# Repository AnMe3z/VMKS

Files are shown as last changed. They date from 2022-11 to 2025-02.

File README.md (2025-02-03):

# MECHKA v1
## By Budget Dynamics

MECHKA е четирикрак робот, който е създаден от екип Budget Dynamics. Той може да изпълнява различни интересни и полезни функции. Роботът има приложения в индустрията и образованието. Контролира се от мобилно приложение чрез Bluetooth. Проекта поначало е курсов проект по дисциплината "Вградени микрокомпютърни системи" - ВМКС, но екипът участва с него и във ТУЕС Фест 2023 (и печели първо място в него в категорията "ВМКС"), както и е приет с MECHKA в "PARA Robotics Incubator" сезон 2. Също участва и в Robo Days '23, където печели второ място в категорията "Роботика".

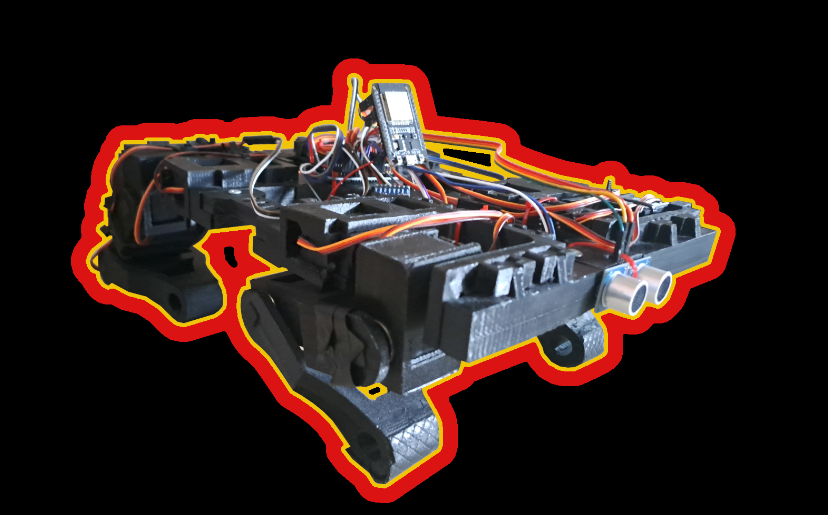
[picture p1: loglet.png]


## Съдържание
 
1. [Функции](#функции)  
2. [Документация на проекта](#Документация-на-проекта)       
3. [Презентация](#презентация)  
4. [Demо](#Demo)     
5. [Технологии](#Технологии)     
6. [Електрическа схема](#Електрическа-схема)   
7. [3D Модел на тялото](#3D-Модел-на-тялото)  
8. [ТУЕС Фест постер](#ТУЕС-Фест-постер)    
9. [Екипът Budget Dynamics](#Budget-Dynamics)  

## Функции

- Управление от мобилно приложение
- Изправяне, клякане
- Ходене
- Специални функции

## Документация на проекта

[Документация](https://docs.google.com/document/d/1ljFhPLfK0vJMqwFt7CCxIXQy4T2rVfxQFEeq_DpqxoI/edit)

## Презентация

[Презентация](https://docs.google.com/presentation/d/1ao5GaoYlJ3WwoU5Bq-MMPqkvP_JQxsr8S0_cT7X9GHs/edit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)

## Demo

[Демонстрация](https://www.youtube.com/watch?v=mcv_eNT28IA&t=1s&ab_channel=%D0%A2%D0%A3%D0%95%D0%A1)

## Технологии

- **Много математика**
- **Arduino Uno**
- **C/C++**
- **Android studio**
- **Java**

## Електрическа схема

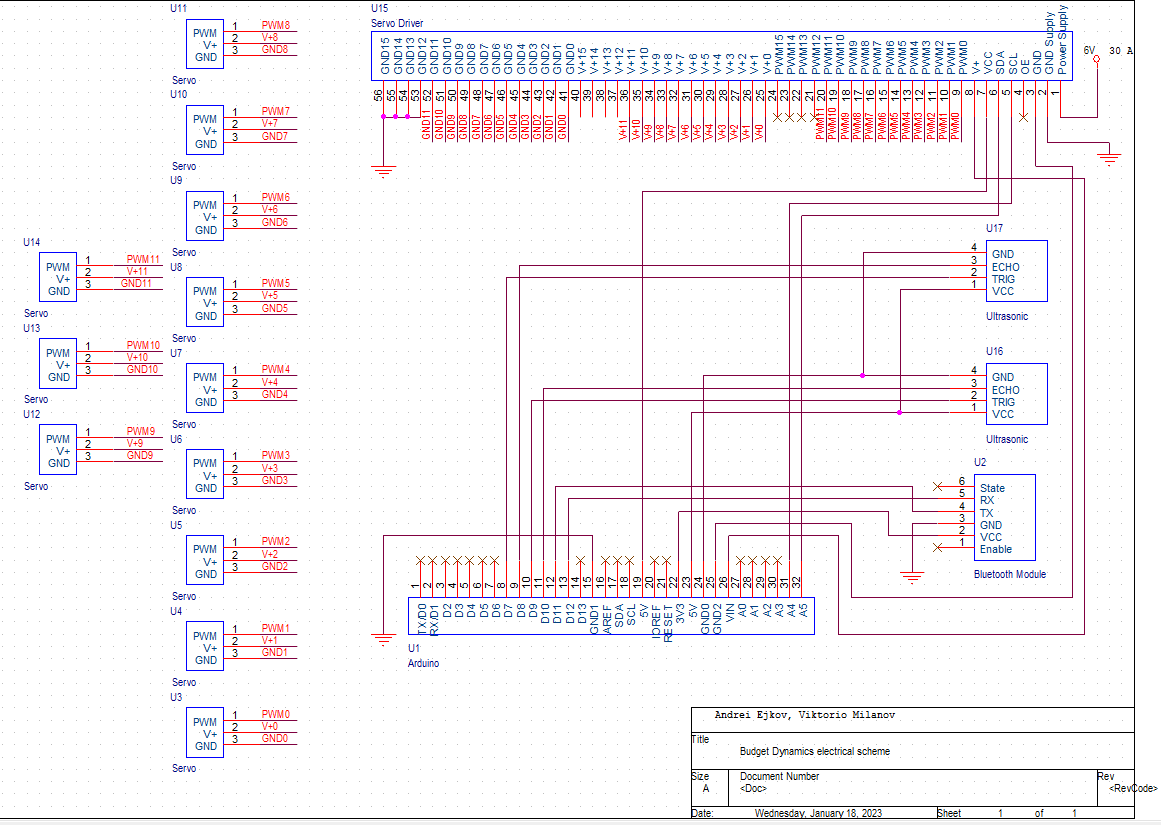
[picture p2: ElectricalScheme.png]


## 3D Модел на тялото

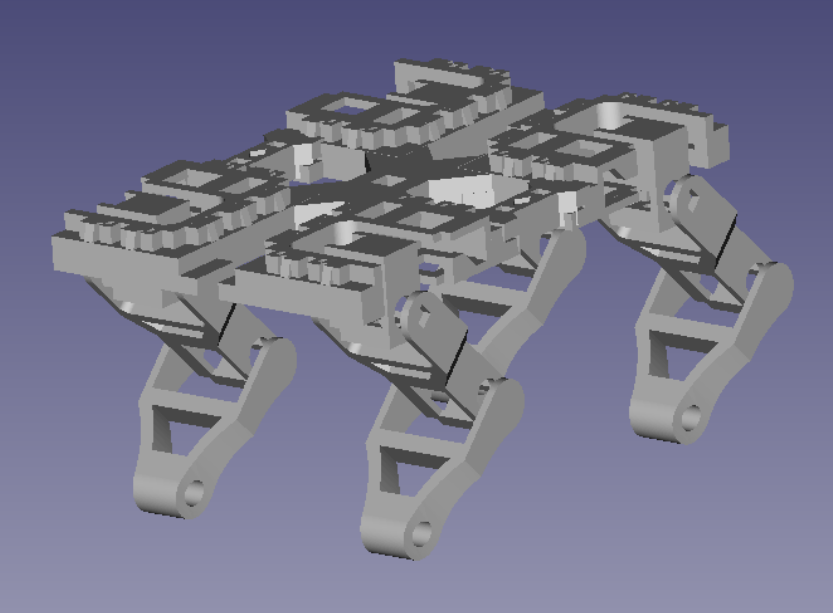
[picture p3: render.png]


## ТУЕС Фест постер



## Budget Dynamics

- [@Андрей Ежков](https://www.github.com/AnMe3z)
- [@Викторио Миланов](https://www.github.com/bigIq)

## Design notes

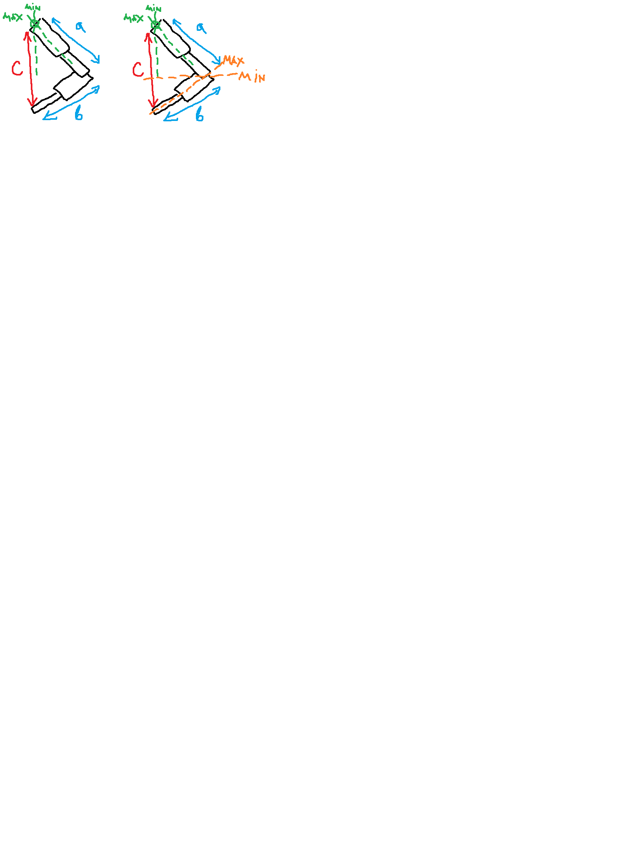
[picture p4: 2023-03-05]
code/other/stage1/servos/servo-lore.png

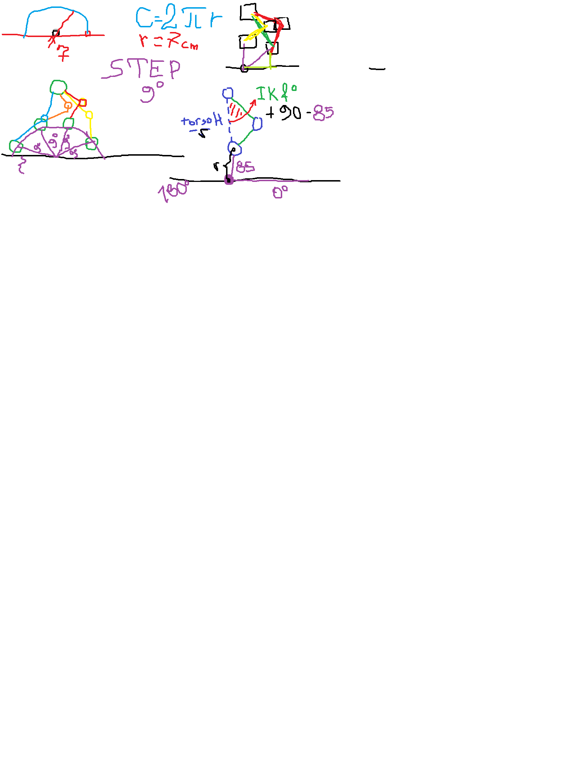
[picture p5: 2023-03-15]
code/other/stage1/servos/servo-walk-lore.png

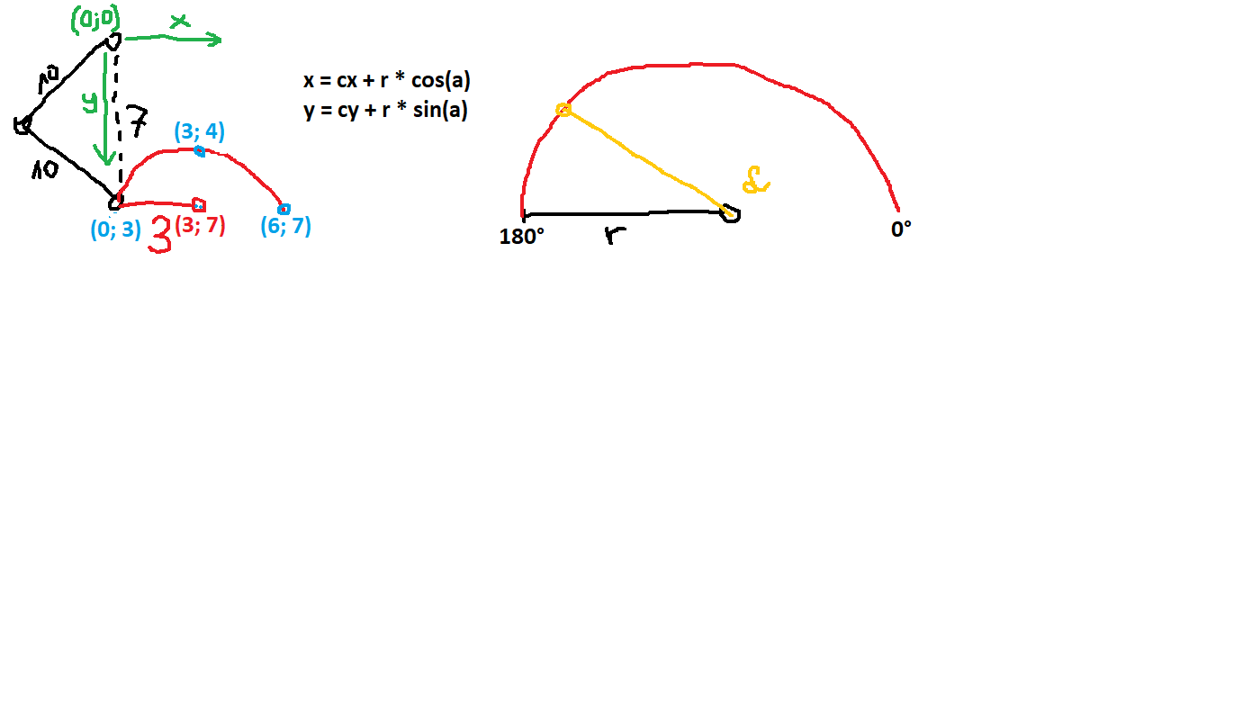
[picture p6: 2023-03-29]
code/other/stage1/servos/hodene-shemi.png

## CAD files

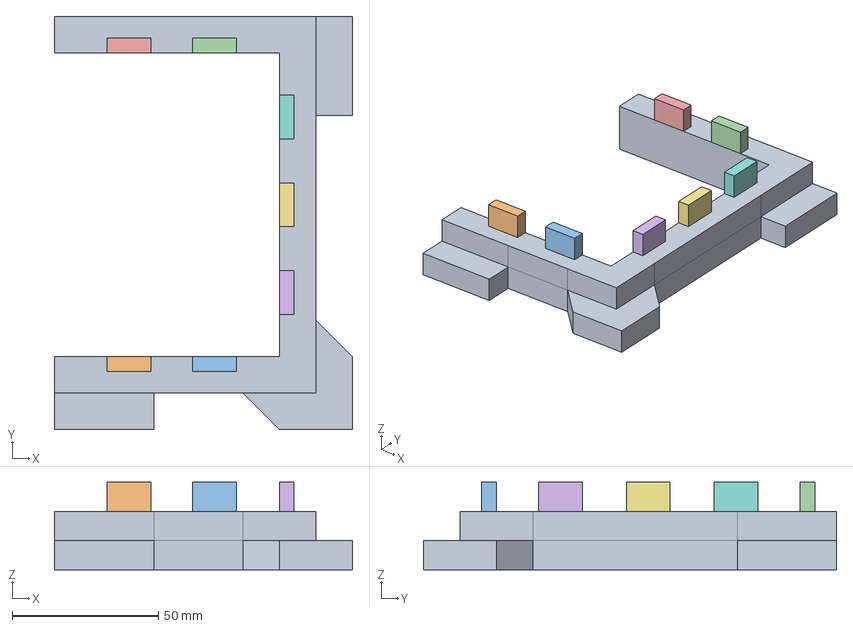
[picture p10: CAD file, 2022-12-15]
hardware/body/HipToBody(Without Full Connectors).FCStd
102.0 x 141.5 x 30.0 mm
MainMale
MaleCon1
MaleCon002
MaleCon004
MaleCon005
MaleCon006
MaleCon007
MaleCon008

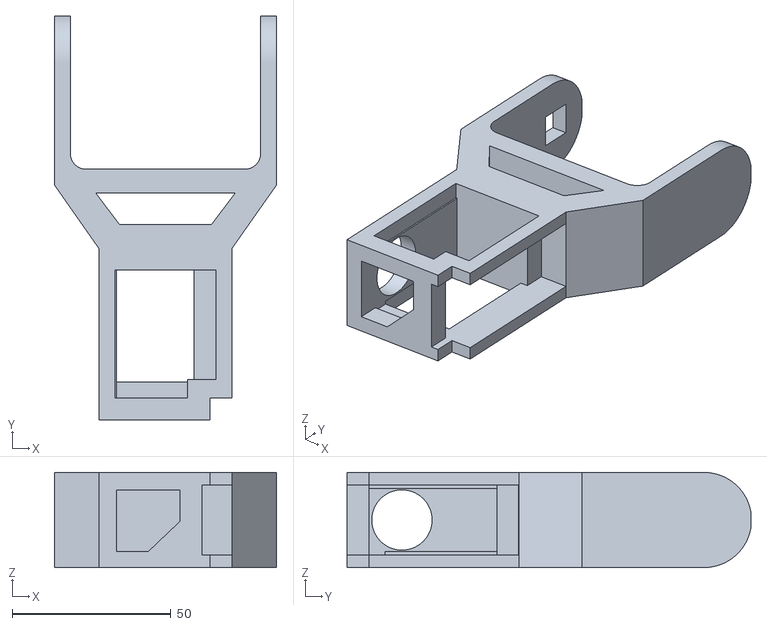
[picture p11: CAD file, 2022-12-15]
hardware/exports/femur-MainBody.stl
70.0 x 127.2 x 30.0

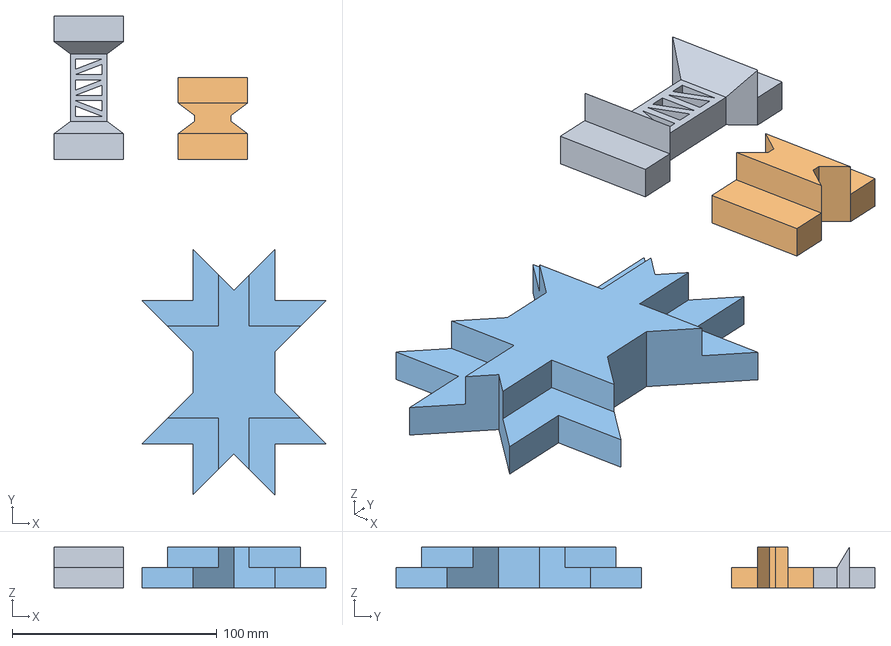
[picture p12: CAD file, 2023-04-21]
hardware/body/OtherBodyParts_Featherweight-fixed.FCStd
132.9 x 234.0 x 20.0 mm
I
I2 (4cm)
Star

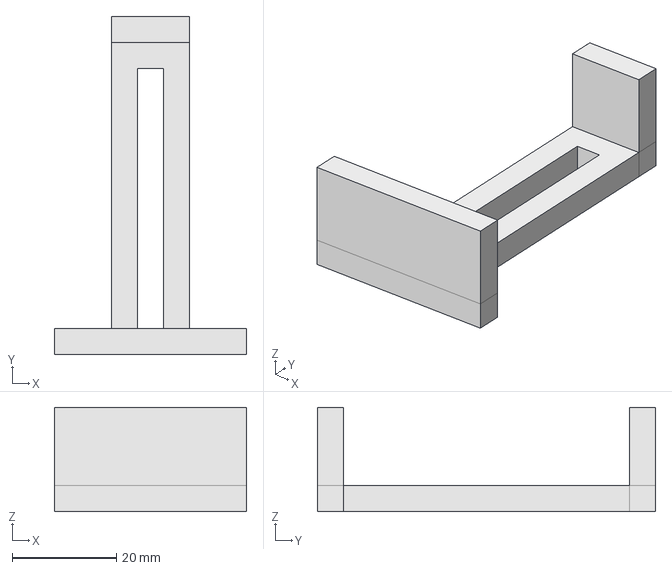
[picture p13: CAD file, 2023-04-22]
hardware/exo(rollcage)/hc-05-holder.FCStd
37.0 x 65.0 x 20.0 mm

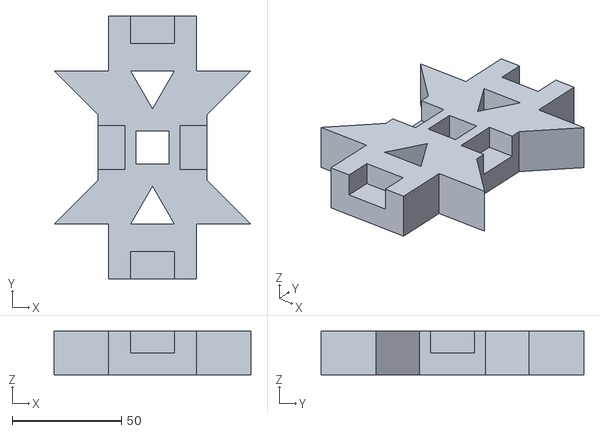
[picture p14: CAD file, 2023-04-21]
hardware/exports/exoskeleton parts-Star.stl
90.0 x 120.0 x 20.0

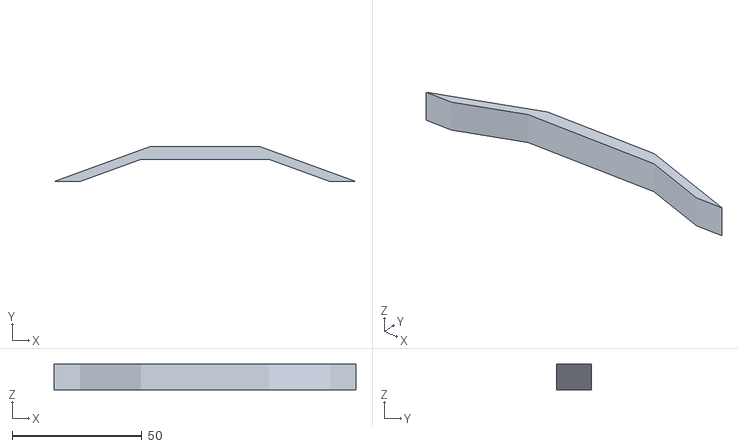
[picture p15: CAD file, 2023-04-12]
hardware/holders/ultrasonicHolderTRUST.stl
116.5 x 13.6 x 10.0

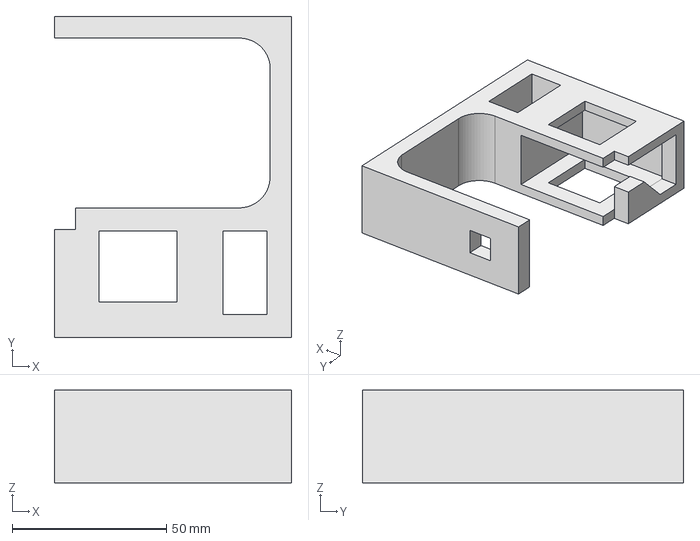
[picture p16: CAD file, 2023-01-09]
hardware/legs/hip-female.FCStd
76.9 x 104.0 x 30.0 mm

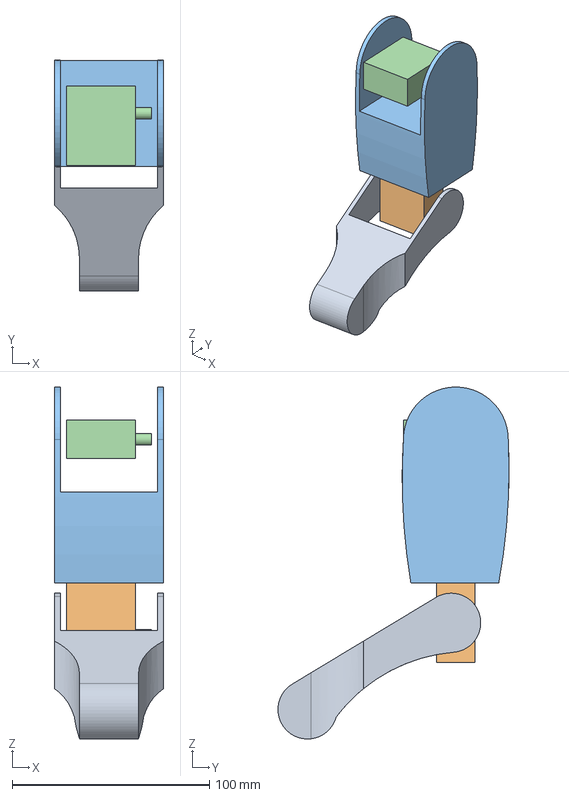
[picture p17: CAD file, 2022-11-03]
hardware/legs/testModels/combinedLeg.FCStd
55.0 x 117.1 x 178.4 mm
lowerLegBody
kneeServoBody
upperLegBody
femurServoBody

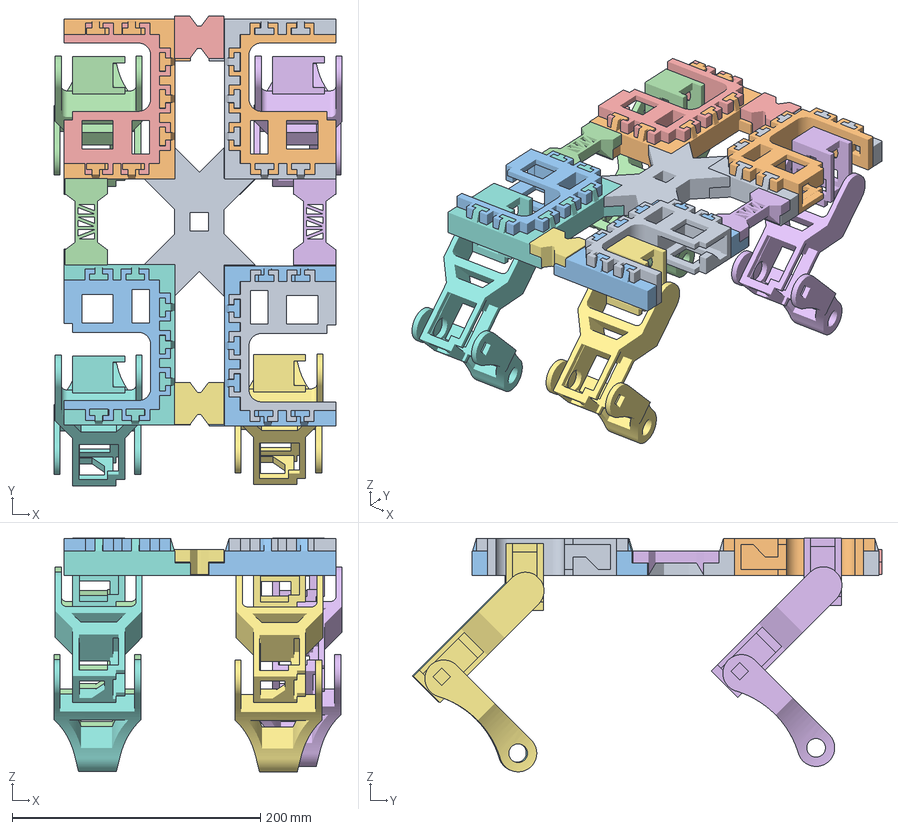
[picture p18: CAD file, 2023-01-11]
hardware/render.FCStd
232.0 x 378.2 x 188.2 mm
Star
HipToBodyFixed (1)
HipToBodyFixed (1)001
leg-render-1
hip-femaleWith_Connectors2-left
leg-render-002
leg-render-003
leg-render-004
hip-femaleWith_Connectors2-left001
hip-femaleWith_Connectors2-right
hip-femaleWith_Connectors2-right001
l1
l2
l003
l004
HipToBodyreversed-fixed-fixedagain
HipToBodyreversed-fixed-fixedagain001

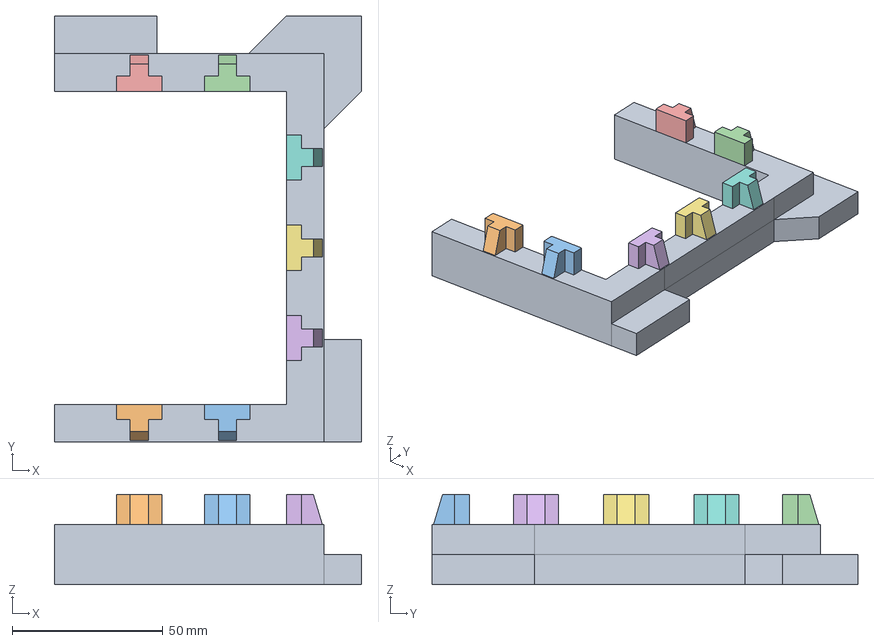
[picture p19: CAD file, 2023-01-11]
hardware/body/HipToBody(reversed-fixed-fixedagain).FCStd
102.0 x 141.5 x 30.0 mm
MainMale
MaleCon1
MaleCon002
MaleCon004
MaleCon005
MaleCon006
MaleCon007
MaleCon008

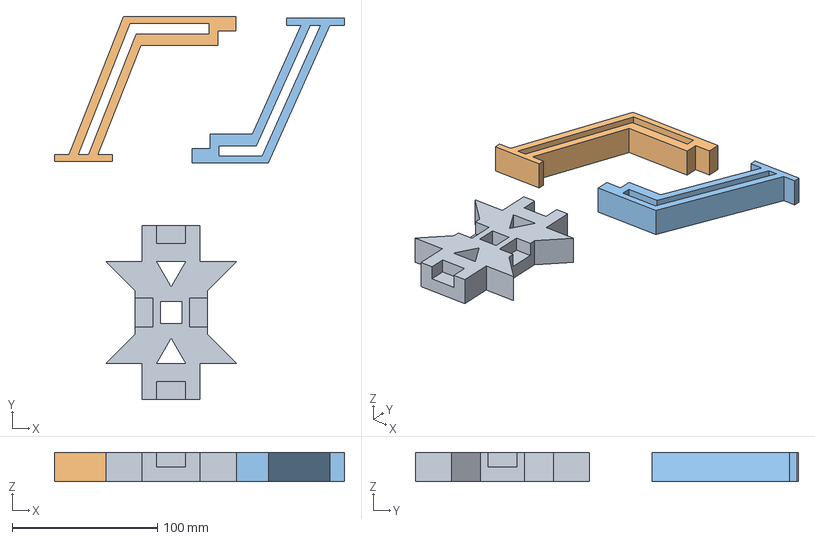
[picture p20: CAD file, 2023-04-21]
hardware/exo(rollcage)/exoskeleton parts.FCStd
199.8 x 264.0 x 20.0 mm
Star
Long part
Short part

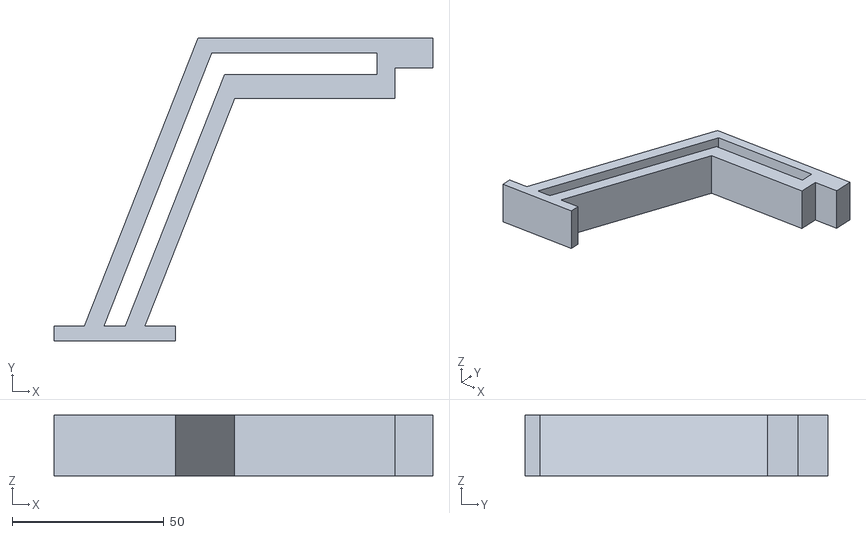
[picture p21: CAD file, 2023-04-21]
hardware/exports/exoskeleton parts-Long part.stl
125.0 x 100.0 x 20.0

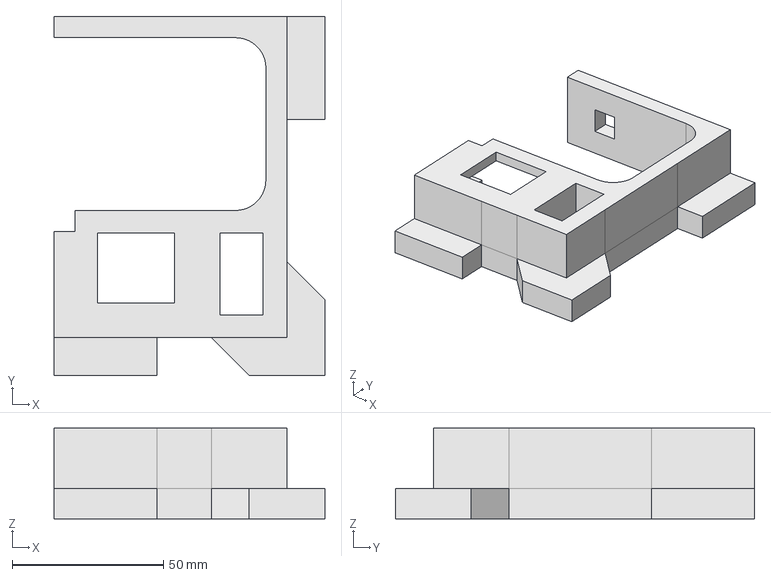
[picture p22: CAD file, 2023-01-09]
hardware/legs/hip-female-v2.FCStd
89.4 x 118.5 x 30.0 mm

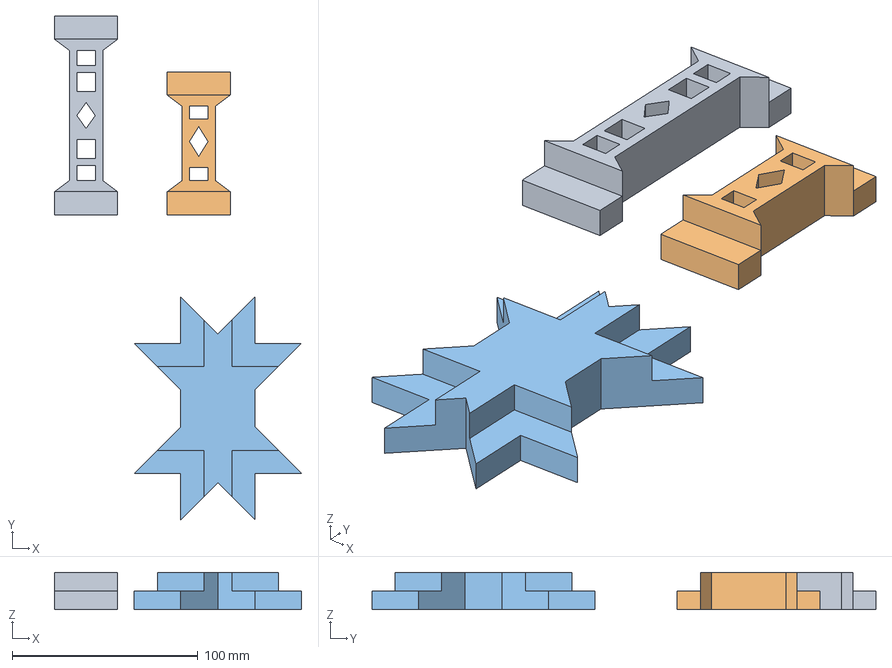
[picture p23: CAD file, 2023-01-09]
hardware/body/OtherBodyParts(Enhanced).FCStd
132.9 x 271.0 x 20.0 mm
I
I2 (4cm)
Star

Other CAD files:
hardware/holders/ultrasonicHolder.FCStd
hardware/exports/exoskeleton parts-Short part.stl
hardware/holders/ultrasonicHolder-Body.stl
hardware/legs/knee.FCStd
hardware/body/HipToBody(reversed).FCStd
hardware/body/HipToBody(reversed-fixed).FCStd
hardware/body/OtherBodyParts-andrey.FCStd
hardware/body/OtherBodyParts.FCStd
hardware/body/hip-female(With Connectors).FCStd
hardware/body/hip-femaleWith_Connectors_Fixed_Positioning (1).FCStd
hardware/exports/HipToBody.stl
hardware/exports/HipToBodyFixed (1).stl
hardware/exports/HipToBodyFixed.stl
hardware/exports/HipToBodyreversed-fixed (2).stl
hardware/exports/HipToBodyreversed-fixed-fixedagain.stl
hardware/exports/OtherBodyParts-I2-4cm.stl
hardware/exports/Star.stl
hardware/exports/Unnamed-hip-femaleWith_Connectors2-right.stl
hardware/exports/hip-female-v2-Body.stl
hardware/exports/hip-female.stl
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

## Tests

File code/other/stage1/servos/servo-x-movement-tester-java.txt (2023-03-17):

/* Online Java Compiler and Editor */
public class HelloWorld{

     public static void main(String []args){
        System.out.println("Hello, World!");
        
        int legLenght = 10;
        int a = legLenght;
        int b = a;
        double c = 9;
        
        double x = 5;
        System.out.println("kneeAngle: " + cosineTheorem(a, b, c));
        System.out.println("femurAngle: " + cosineTheorem(a, c, b));
        
        System.out.println(" --- --- ---");
        double theta = Math.toDegrees(Math.atan(Math.tan(x/c)));
        System.out.println("theta degrees: " + theta);
        
        System.out.println(" --- --- ---");
        
        System.out.println("c new: " + c / Math.cos(theta));
        
        // inverseKinematicsXMovement(1, 10, 1);
        // inverseKinematicsXMovement(1, 10, 2);
     }
     
     public static void inverseKinematicsXMovement(int legIndex, double torsoHeight, double xMovement){
        System.out.println("Inputs: ");
        System.out.println("legIndex: " + legIndex);
        System.out.println("torsoHeight: " + torsoHeight);
        System.out.println("xMovement: " + xMovement);
        System.out.println(" --- --- ---");
        // theta is the femur offset angle that is added  to the inverse kinematics
          double theta = Math.toDegrees(Math.atan(Math.tan(xMovement / torsoHeight)));
        //   double theta = Math.pow(Math.tan(xMovement / torsoHeight), -1);
        System.out.println("theta: " + theta);
          double cNew = torsoHeight / Math.cos(theta);
        System.out.println("cNew: " + cNew);
        System.out.println(" --- --- ---");
        
          // --- inverse kinematics with offset
          double a = 10;
        System.out.println("a: " + a);
          double b = a;
        System.out.println("b: " + b);
          double c = torsoHeight;
        System.out.println("c: " + c);
        System.out.println(" --- --- ---");
        
          double kneeAngle = cosineTheorem(a, b, c)/2.0;
        System.out.println("kneeAngle: " + kneeAngle);
          double femurAngle =cosineTheorem(a, c, b)/2.0;
        System.out.println("kneeAngle: " + kneeAngle);
        System.out.println(" --- --- ---");
        
          //knee
        System.out.println("Knee final angle: " + (3 + kneeAngle));
          
          //femur
        System.out.println("Femur final angle: " + (156 - femurAngle - theta));
        System.out.println(" --- --- ---");
        System.out.println(" --- --- ---");
        System.out.println(" --- --- ---");
     }
     
     public static double cosineTheorem(double a, double b, double c){
          if (c == 0){
            return 0;
          }
          else{
            return Math.acos((b * b + a * a - c * c)/(2.0 * b * a)) * 57296 / 1000;
          }
    }
}

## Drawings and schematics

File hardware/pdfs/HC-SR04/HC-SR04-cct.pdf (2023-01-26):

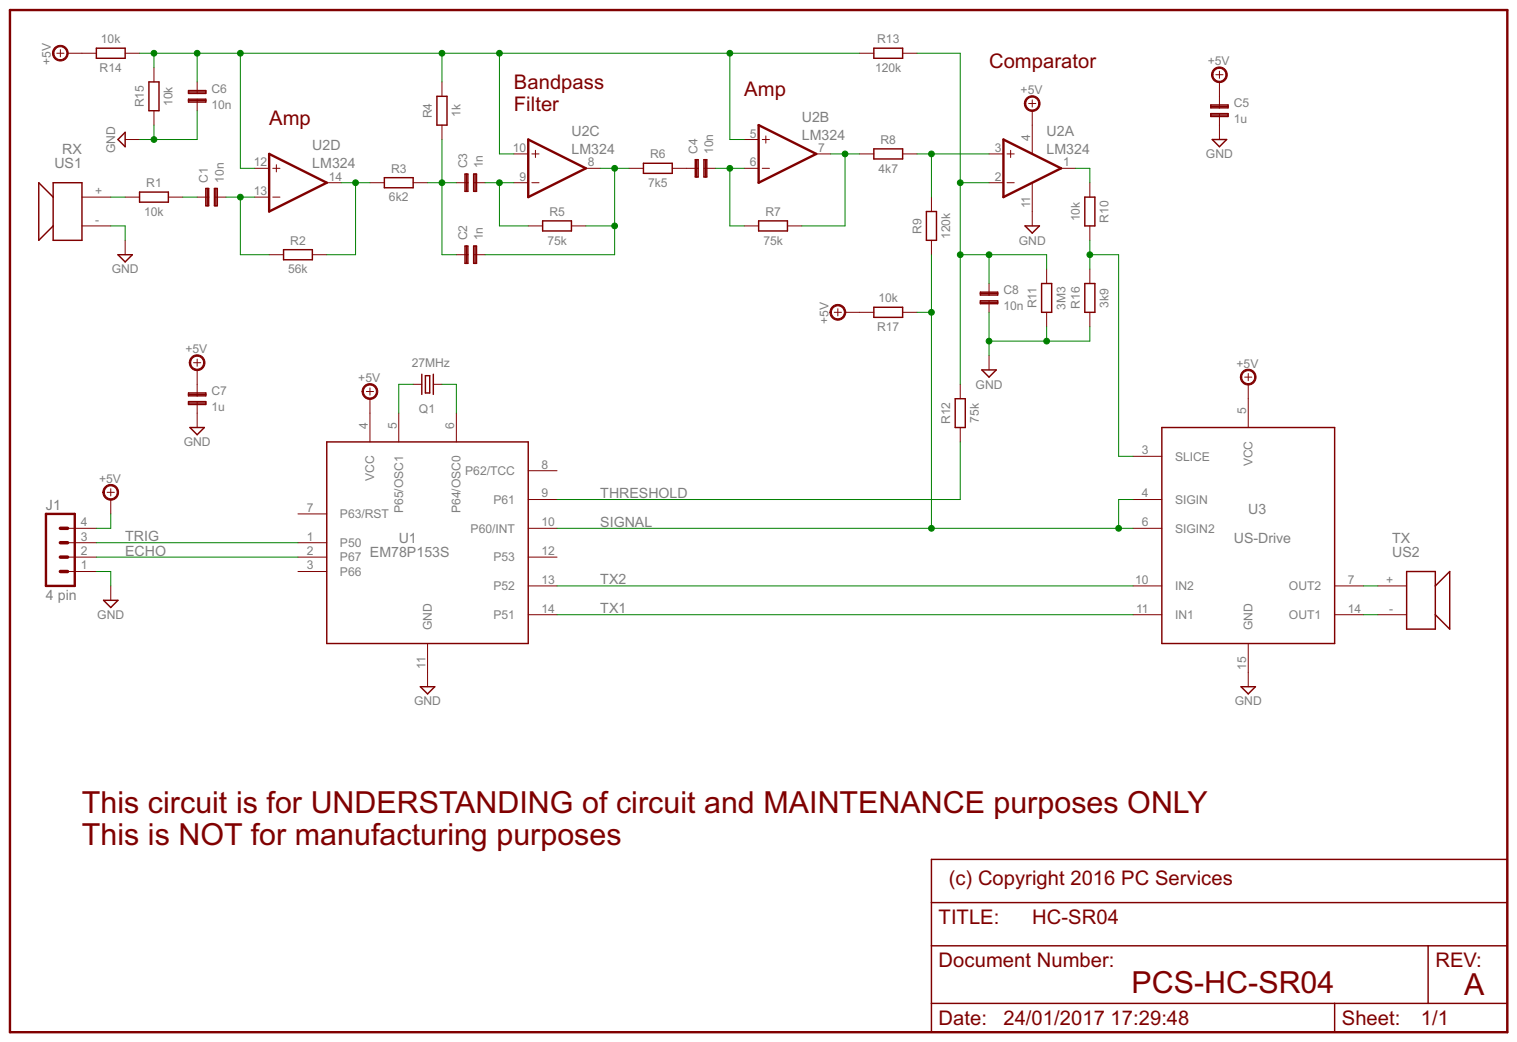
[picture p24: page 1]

This circuit is for UNDERSTANDING of circuit and MAINTENANCE purposes ONLY
This is NOT for manufacturing purposes

Document Number: PCS-HC-SR04 | REV: A

Date: 24/01/2017 17:29:48 | Sheet: 1/1

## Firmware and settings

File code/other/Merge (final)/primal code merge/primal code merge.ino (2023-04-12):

#include<HCPCA9685.h>
#include<SoftwareSerial.h>

//must have:
// - array with min and max values
// - inverse kinematics

#define  I2CAdd 0x40
HCPCA9685 HCPCA9685(I2CAdd);

char receivedValueBT;

/* Create object named bt of the class SoftwareSerial */ 
SoftwareSerial bt(10,11); /* (Rx,Tx) */	

//int servoRoms[12][12] = {{72, 180}, {22, 170}, {0, 0}, {10, 140}, {0, 180}, {0, 0}, {0, 70}, {35, 70}, {0, 0}, {10, 60}, {35, 140}, {0, 0}};
//                      c             c           c            c           c           c           c             c
int servoRoms[4][6] = {{40, 180, 90, 150, 35, 0}, {3, 120, 85, 135, 75, 0}, {0, 115, 90, 150, 85, 0}, {0, 115, 100, 160, 90, 0}};
//the legs need to be closed at the start of the program for the angles to be true
int servoCurrentAngles[4][3] = {{40, 170, 0}, {3, 156, 0}, {0, 150, 0}, {0, 180, 0}};
int leg[4][3] = {{0, 1, 2}, {3, 4, 5}, {6, 7, 8}, {9, 10, 11}};

int legLenght = 10;

double x[4] = {0 ,0, 0, 0};
double height = 1;
double y[4] = {0 ,0, 0, 0};

//all functions predeclaration
// complex movements
void walk(int speed);
void walkTrust(int speed);
void walkReverse(int speed);
// basic movements
void standDown();
void standUp(double targetHeight);
void xMovement(double tX);
void hold();
void xTestMovement();
void pitchTestMovement();
// essential movements
void inverseKinematics(int legIndex, double torsoHeight, double x);
double cosineTheorem(int a, int b, double c);

void setup() {
  //init the servo driver
  HCPCA9685.Init(SERVO_MODE);
  HCPCA9685.Sleep(false);
  bt.begin(9600);	/* Define baud rate for software serial communication */
  Serial.begin(9600);	/* Define baud rate for serial communication */

  //what i want:
  // - when the program starts move the body to lowered position
  // - stand up

  //make the robot to sit down (be humble)
  standUp(5);
  standDown();
  standUp(5);
  
  // init pause
  delay(750);
}

void loop() {


 if (bt.available()) 
  {
    receivedValueBT = bt.read();
    if (receivedValueBT == '1')
      {
        Serial.write("One");
        walk(50);
      }
    else if (receivedValueBT == '2')
      {
        Serial.write("Two");
      }
    else if (receivedValueBT == '3')
      {
        Serial.write("Three");
      }
    else if (receivedValueBT == '4')
      {
        Serial.write("Four");
        walkReverse(50);
      }
    else if (receivedValueBT == '5')
      {
        Serial.write("Five");
        standUp(5);
      }
    else if (receivedValueBT == '6')
      {
        Serial.write("Six");
        standDown();
      }
    else if (receivedValueBT == '7')
      {
        Serial.write("Seven");
        xTestMovement();
      }
    else if (receivedValueBT == '8')
      {
        Serial.write("Eight");
        pitchTestMovement();
      }
    else if (receivedValueBT == '9')
      {
        Serial.write("Nine");
      }

  }
  //walkReverse(50);

  // y[0] = 5;
  // x[0] = 0;
  // y[1] = 5;
  // x[1] = 0;
  // y[2] = 5;
  // x[2] = 0;
  // y[3] = 5;
  // x[3] = 0;
  // inverseKinematics(0, y[0], x[0]);
  // inverseKinematics(1, y[1], x[1]);
  // inverseKinematics(2, y[2], x[2]);
  // inverseKinematics(3, y[3], x[3]);
  // delay(500);

  //walk(50);

  // walkTrust(50);

  // y[0] = 5;0
  // x[0] = 0;
  // y[1] = 5;
  // x[1] = 0;
  // y[2] = 5;
  // x[2] = 0;
  // y[3] = 5;
  // x[3] = 0;
  // inverseKinematics(0, y[0], x[0]);
  // inverseKinematics(1, y[1], x[1]);
  // inverseKinematics(2, y[2], x[2]);
  // inverseKinematics(3, y[3], x[3]);
  // delay(150);
  
  // walk(50);

  
  // y[0] = 5;
  // x[0] = 0;
  // y[1] = 5;
  // x[1] = 0;
  // y[2] = 5;
  // x[2] = 0;
  // y[3] = 5;
  // x[3] = 0;
  // inverseKinematics(0, y[0], x[0]);
  // inverseKinematics(1, y[1], x[1]);
  // inverseKinematics(2, y[2], x[2]);
  // inverseKinematics(3, y[3], x[3]);
  // delay(150);
  
  // walkTrust(50);

  
  // y[0] = 5;
  // x[0] = 0;
  // y[1] = 5;
  // x[1] = 0;
  // y[2] = 5;
  // x[2] = 0;
  // y[3] = 5;
  // x[3] = 0;
  // inverseKinematics(0, y[0], x[0]);
  // inverseKinematics(1, y[1], x[1]);
  // inverseKinematics(2, y[2], x[2]);
  // inverseKinematics(3, y[3], x[3]);
  // delay(150);
  
  // walk(50);

  
  // y[0] = 5;
  // x[0] = 0;
  // y[1] = 5;
  // x[1] = 0;
  // y[2] = 5;
  // x[2] = 0;
  // y[3] = 5;
  // x[3] = 0;
  // inverseKinematics(0, y[0], x[0]);
  // inverseKinematics(1, y[1], x[1]);
  // inverseKinematics(2, y[2], x[2]);
  // inverseKinematics(3, y[3], x[3]);
  // delay(150);
  
  // walkTrust(50);

  
  // y[0] = 5;
  // x[0] = 0;
  // y[1] = 5;
  // x[1] = 0;
  // y[2] = 5;
  // x[2] = 0;
  // y[3] = 5;
  // x[3] = 0;
  // inverseKinematics(0, y[0], x[0]);
  // inverseKinematics(1, y[1], x[1]);
  // inverseKinematics(2, y[2], x[2]);
  // inverseKinematics(3, y[3], x[3]);
  // delay(150);
  
  // walk(50);

  
  // y[0] = 5;
  // x[0] = 0;
  // y[1] = 5;
  // x[1] = 0;
  // y[2] = 5;
  // x[2] = 0;
  // y[3] = 5;
  // x[3] = 0;
  // inverseKinematics(0, y[0], x[0]);
  // inverseKinematics(1, y[1], x[1]);
  // inverseKinematics(2, y[2], x[2]);
  // inverseKinematics(3, y[3], x[3]);
  // delay(150);
  
  // walkTrust(50);

  
  // y[0] = 5;
  // x[0] = 0;
  // y[1] = 5;
  // x[1] = 0;
  // y[2] = 5;
  // x[2] = 0;
  // y[3] = 5;
  // x[3] = 0;
  // inverseKinematics(0, y[0], x[0]);
  // inverseKinematics(1, y[1], x[1]);
  // inverseKinematics(2, y[2], x[2]);
  // inverseKinematics(3, y[3], x[3]);
  // delay(150);
  
  // walk(50);

  
  // y[0] = 5;
  // x[0] = 0;
  // y[1] = 5;
  // x[1] = 0;
  // y[2] = 5;
  // x[2] = 0;
  // y[3] = 5;
  // x[3] = 0;
  // inverseKinematics(0, y[0], x[0]);
  // inverseKinematics(1, y[1], x[1]);
  // inverseKinematics(2, y[2], x[2]);
  // inverseKinematics(3, y[3], x[3]);
  // delay(150);
  
  // walkTrust(50);
  
  delay(100);

  //standDown();
  
}

// --- complex movements

void walk(int speed){
  int archSteps = 10;
  double angle = 180;
  double radius = 1;

  //legs upward drift
  int count = 0;
  bool rising = true;
  double lUDStep = radius/2;

  //legs drift step
  double lDStep = (2 * radius) / (angle / archSteps);

  //pitch 
  // y[2] -= 1;
  // y[3] -= 1;
  // inverseKinematics(2, y[2], x[2]);
  // inverseKinematics(3, y[3], x[3]);
  // delay(speed);
  
  double cx[4] = {x[0] + radius/2, x[1] + radius/2, x[2] + radius/2, x[3] + radius/2};
  double cy[4] = {y[0], y[1], y[2], y[3]};

  while(angle > 0){
    angle -= 180/archSteps;

    x[1] = cx[1] + radius * cos((angle * 71) / 4068);
    y[1] = cy[1] - radius * sin((angle * 71) / 4068);
    inverseKinematics(1, y[1], x[1]);

    x[2] = cx[2] + radius * cos((angle * 71) / 4068);
    y[2] = cy[2] - radius * sin((angle * 71) / 4068);
    inverseKinematics(2, y[2], x[2]);

    //leg drift
    if(count < 6 && rising){
      count++;
      if(count == 6){
        rising = false;
      }
    }

    if(rising){
      y[0] += lUDStep*0.75;
      y[3] += lUDStep*0.75;
    }
    else{
      y[0] -= lUDStep*0.75;
      y[3] -= lUDStep*0.75;
    }

    x[0] -= lDStep/2;
    inverseKinematics(0, y[0], x[0]);
    x[3] -= lDStep/2;
    inverseKinematics(3, y[3], x[3]);

    delay(speed);
  }

  // reset the angle
  angle = 180;
  count = 0;
  rising = true;
  y[1] = height;
  y[2] = height;
  double bx[4] = {x[0] + radius, x[1] + radius, x[2] + radius, x[3] + radius};
  double by[4] = {y[0], y[1], y[2], y[3]};
  memcpy(cx, bx, sizeof(cx));
  memcpy(cy, by, sizeof(cy));
  
  while(angle > 0){ // loops 10 times
    angle -= 180/archSteps;

    x[0] = cx[0] + radius * cos((angle * 71) / 4068);
    y[0] = cy[0] - (radius * 1.4) * sin((angle * 71) / 4068);
    inverseKinematics(0, y[0], x[0]);

    x[3] = cx[3] + radius * cos((angle * 71) / 4068);
    y[3] = cy[3] - (radius * 1.4) * sin((angle * 71) / 4068);
    inverseKinematics(3, y[3], x[3]);

    //leg drift
    if(count < 6 && rising){
      count++;
      if(count == 6){
        rising = false;
      }
    }

    if(rising){
      y[1] += lUDStep;
      y[2] += lUDStep;
    }
    else{
      y[1] -= lUDStep;
      y[2] -= lUDStep;
    }

    x[1] -= lDStep;
    inverseKinematics(1, y[1], x[1]);
    x[2] -= lDStep;
    inverseKinematics(2, y[2], x[2]);

    delay(speed);
  }
  
  // // reset variables
  angle = 180;
  y[0] = height;
  y[3] = height;
  double ax[4] = {x[0] + radius/2, x[1] + radius/2, x[2] + radius/2, x[3] + radius/2};
  double ay[4] = {y[0], y[1], y[2], y[3]};
  memcpy(cx, ax, sizeof(cx));
  memcpy(cy, ay, sizeof(cy));

  while(angle > 180){
    angle -= 180/archSteps;

    x[1] = cx[1] + radius * cos((angle * 71) / 4068);
    y[1] = cy[1] - radius * sin((angle * 71) / 4068);
    inverseKinematics(1, y[1], x[1]);

    x[2] = cx[2] + radius * cos((angle * 71) / 4068);
    y[2] = cy[2] - radius * sin((angle * 71) / 4068);
    inverseKinematics(2, y[2], x[2]);


    //leg drift
    if(count < 6 && rising){
      count++;
      if(count == 6){
        rising = false;
      }
    }

    if(rising){
      y[0] += lUDStep*0.75;
      y[3] += lUDStep*0.75;
    }
    else{
      y[0] -= lUDStep*0.75;
      y[3] -= lUDStep*0.75;
    }

    inverseKinematics(0, y[0], x[0]);
    inverseKinematics(3, y[3], x[3]);

    delay(150);
  }
  
  
}

void walkTrust(int speed){
  int archSteps = 10;
  double angle = 180;
  double radius = 1;

  //legs upward drift
  int count = 0;
  bool rising = true;
  double lUDStep = radius/2;

  //legs drift step
  double lDStep = (2 * radius) / (angle / archSteps);

  //pitch 
  // y[2] -= 1;
  // y[3] -= 1;
  // inverseKinematics(2, y[2], x[2]);
  // inverseKinematics(3, y[3], x[3]);
  // delay(speed);
  
  double cx[4] = {x[0] + radius/2, x[1] + radius/2, x[2] + radius/2, x[3] + radius/2};
  double cy[4] = {y[0], y[1], y[2], y[3]};

  while(angle > 0){
    angle -= 180/archSteps;

    x[0] = cx[0] + radius * cos((angle * 71) / 4068);
    y[0] = cy[0] - (radius * 1.4) * sin((angle * 71) / 4068);
    inverseKinematics(0, y[0], x[0]);

    x[3] = cx[3] + radius * cos((angle * 71) / 4068);
    y[3] = cy[3] - (radius * 1.4) * sin((angle * 71) / 4068);
    inverseKinematics(3, y[3], x[3]);

    //leg drift
    if(count < 6 && rising){
      count++;
      if(count == 6){
        rising = false;
      }
    }

    if(rising){
      y[1] += lUDStep;
      y[2] += lUDStep;
    }
    else{
      y[1] -= lUDStep;
      y[2] -= lUDStep;
    }

    x[1] -= lDStep;
    inverseKinematics(1, y[1], x[1]);
    x[2] -= lDStep;
    inverseKinematics(2, y[2], x[2]);

    delay(speed);
  }

  // reset the angle
  angle = 180;
  count = 0;
  rising = true;
  y[1] = height;
  y[2] = height;
  double bx[4] = {x[0] + radius, x[1] + radius, x[2] + radius, x[3] + radius};
  double by[4] = {y[0], y[1], y[2], y[3]};
  memcpy(cx, bx, sizeof(cx));
  memcpy(cy, by, sizeof(cy));
  
  while(angle > 0){ // loops 10 times
    angle -= 180/archSteps;

    x[1] = cx[1] + radius * cos((angle * 71) / 4068);
    y[1] = cy[1] - radius * sin((angle * 71) / 4068);
    inverseKinematics(1, y[1], x[1]);

    x[2] = cx[2] + radius * cos((angle * 71) / 4068);
    y[2] = cy[2] - radius * sin((angle * 71) / 4068);
    inverseKinematics(2, y[2], x[2]);

    //leg drift
    if(count < 6 && rising){
      count++;
      if(count == 6){
        rising = false;
      }
    }

    if(rising){
      y[0] += lUDStep*0.75;
      y[3] += lUDStep*0.75;
    }
    else{
      y[0] -= lUDStep*0.75;
      y[3] -= lUDStep*0.75;
    }

    x[0] -= lDStep/2;
    inverseKinematics(0, y[0], x[0]);
    x[3] -= lDStep/2;
    inverseKinematics(3, y[3], x[3]);
    delay(speed);
  }
  
  // // reset variables
  angle = 180;
  y[0] = height;
  y[3] = height;
  double ax[4] = {x[0] + radius/2, x[1] + radius/2, x[2] + radius/2, x[3] + radius/2};
  double ay[4] = {y[0], y[1], y[2], y[3]};
  memcpy(cx, ax, sizeof(cx));
  memcpy(cy, ay, sizeof(cy));

  while(angle > 180){
    angle -= 180/archSteps;

    x[0] = cx[0] + radius * cos((angle * 71) / 4068);
    y[0] = cy[0] - radius * sin((angle * 71) / 4068);
    inverseKinematics(0, y[0], x[0]);

    x[3] = cx[3] + radius * cos((angle * 71) / 4068);
    y[3] = cy[3] - radius * sin((angle * 71) / 4068);
    inverseKinematics(3, y[3], x[3]);


    //leg drift
    if(count < 6 && rising){
      count++;
      if(count == 6){
        rising = false;
      }
    }

    if(rising){
      y[1] += lUDStep*0.75;
      y[2] += lUDStep*0.75;
    }
    else{
      y[1] -= lUDStep*0.75;
      y[2] -= lUDStep*0.75;
    }

    inverseKinematics(1, y[1], x[1]);
    inverseKinematics(2, y[2], x[2]);

    delay(150);
  }
  
  
}

void walkReverse(int speed){
int archSteps = 10;
  double angle = 180;
  double radius = 1;

  //legs upward drift
  int count = 0;
  bool rising = true;
  double lUDStep = radius/2;

  //legs drift step
  double lDStep = (2 * radius) / (angle / archSteps);
  
  double cx[4] = {x[0] - radius/2, x[1] - radius/2, x[2] - radius/2, x[3] - radius/2};
  double cy[4] = {y[0], y[1], y[2], y[3]};

  while(angle > 0){
    angle -= 180/archSteps;

    x[1] = cx[1] - radius * cos((angle * 71) / 4068);
    y[1] = cy[1] - radius * sin((angle * 71) / 4068);
    inverseKinematics(1, y[1], x[1]);

    x[2] = cx[2] - radius * cos((angle * 71) / 4068);
    y[2] = cy[2] - radius * sin((angle * 71) / 4068);
    inverseKinematics(2, y[2], x[2]);

    //leg drift
    if(count < 6 && rising){
      count++;
      if(count == 6){
        rising = false;
      }
    }

    if(rising){
      y[0] += lUDStep*0.75;
      y[3] += lUDStep*0.75;
    }
    else{
      y[0] -= lUDStep*0.75;
      y[3] -= lUDStep*0.75;
    }

    x[0] += lDStep/2;
    inverseKinematics(0, y[0], x[0]);
    x[3] += lDStep/2;
    inverseKinematics(3, y[3], x[3]);

    delay(speed);
  }

  // reset the angle
  angle = 180;
  count = 0;
  rising = true;
  y[1] = height;
  y[2] = height;
  double bx[4] = {x[0] - radius, x[1] - radius, x[2] - radius, x[3] - radius};
  double by[4] = {y[0], y[1], y[2], y[3]};
  memcpy(cx, bx, sizeof(cx));
  memcpy(cy, by, sizeof(cy));
  
  while(angle > 0){ // loops 10 times
    angle -= 180/archSteps;

    x[0] = cx[0] - radius * cos((angle * 71) / 4068);
    y[0] = cy[0] - (radius * 1.4) * sin((angle * 71) / 4068);
    inverseKinematics(0, y[0], x[0]);

    x[3] = cx[3] - radius * cos((angle * 71) / 4068);
    y[3] = cy[3] - (radius * 1.4) * sin((angle * 71) / 4068);
    inverseKinematics(3, y[3], x[3]);

    //leg drift
    if(count < 6 && rising){
      count++;
      if(count == 6){
        rising = false;
      }
    }

    if(rising){
      y[1] += lUDStep;
      y[2] += lUDStep;
    }
    else{
      y[1] -= lUDStep;
      y[2] -= lUDStep;
    }

    x[1] += lDStep;
    inverseKinematics(1, y[1], x[1]);
    x[2] += lDStep;
    inverseKinematics(2, y[2], x[2]);

    delay(speed);
  }
  
  // // reset variables
  angle = 180;
  y[0] = height;
  y[3] = height;
  double ax[4] = {x[0] - radius/2, x[1] - radius/2, x[2] - radius/2, x[3] - radius/2};
  double ay[4] = {y[0], y[1], y[2], y[3]};
  memcpy(cx, ax, sizeof(cx));
  memcpy(cy, ay, sizeof(cy));

  while(angle > 180){
    angle -= 180/archSteps;

    x[1] = cx[1] - radius * cos((angle * 71) / 4068);
    y[1] = cy[1] - radius * sin((angle * 71) / 4068);
    inverseKinematics(1, y[1], x[1]);

    x[2] = cx[2] - radius * cos((angle * 71) / 4068);
    y[2] = cy[2] - radius * sin((angle * 71) / 4068);
    inverseKinematics(2, y[2], x[2]);


    //leg drift
    if(count < 6 && rising){
      count++;
      if(count == 6){
        rising = false;
      }
    }

    if(rising){
      y[0] += lUDStep*0.75;
      y[3] += lUDStep*0.75;
    }
    else{
      y[0] -= lUDStep*0.75;
      y[3] -= lUDStep*0.75;
    }

    inverseKinematics(0, y[0], x[0]);
    inverseKinematics(3, y[3], x[3]);

    delay(150);
  }
}

// --- basic movements

void standUp(double targetHeight){
  double servoStep = 0.25;
  int delayTime = 50;
  
  while(height < targetHeight){ // assume all y's are equal
    height += servoStep;
    y[0] += servoStep;
    y[1] += servoStep;
    y[2] += servoStep;
    y[3] += servoStep;
    inverseKinematics(0, y[0], 0);
    inverseKinematics(1, y[1], 0);
    inverseKinematics(2, y[2], 0);
    inverseKinematics(3, y[3], 0);
    delay(delayTime);
  }
}

void standDown(){
  double servoStep = 0.25;
  int delayTime = 50;
  
  while(height > 0){// assume all y's are equal
    height -= servoStep;
    y[0] -= servoStep;
    y[1] -= servoStep;
    y[2] -= servoStep;
    y[3] -= servoStep;
    inverseKinematics(0, y[0], 0);
    inverseKinematics(1, y[1], 0);
    inverseKinematics(2, y[2], 0);
    inverseKinematics(3, y[3], 0);
    delay(delayTime);
  }
}

void xMovement(double tX){
  double cX = x[0]; // current x
  double servoStep = 0.25;
  int delayTime = 50;
  
  if(cX < tX){
    while(x[0] < tX){
      cX += servoStep;
      x[0] += servoStep;
      x[1] += servoStep;
      x[2] += servoStep;
      x[3] += servoStep;
      inverseKinematics(0, y[0], x[0]);
      inverseKinematics(1, y[1], x[1]);
      inverseKinematics(2, y[2], x[2]);
      inverseKinematics(3, y[3], x[3]);
      delay(delayTime);
    }
  }
  else{
    while(cX > tX){
      cX -= servoStep;
      x[0] -= servoStep;
      x[1] -= servoStep;
      x[2] -= servoStep;
      x[3] -= servoStep;
      inverseKinematics(0, y[0], x[0]);
      inverseKinematics(1, y[1], x[1]);
      inverseKinematics(2, y[2], x[2]);
      inverseKinematics(3, y[3], x[3]);
      delay(delayTime);
    }
  }

  delay(1000);
}

void hold(){
  int delayTime = 50;
  
  inverseKinematics(0, height, 0);
  inverseKinematics(1, height, 0);
  inverseKinematics(2, height, 0);
  inverseKinematics(3, height, 0);

  delay(delayTime);
}

void xTestMovement(){
  double servoStep = 0.25;
  int delayTime = 50;
  double tX = x[0];
  
  while(tX > -2){
    tX -= servoStep;
    x[0] -= servoStep;
    x[1] -= servoStep;
    x[2] -= servoStep;
    x[3] -= servoStep;
    inverseKinematics(0, y[0], x[0]);
    inverseKinematics(1, y[1], x[1]);
    inverseKinematics(2, y[2], x[2]);
    inverseKinematics(3, y[3], x[3]);
    delay(delayTime);
  }
  
  while(tX < 2){
    tX += servoStep;
    x[0] += servoStep;
    x[1] += servoStep;
    x[2] += servoStep;
    x[3] += servoStep;
    inverseKinematics(0, y[0], x[0]);
    inverseKinematics(1, y[1], x[1]);
    inverseKinematics(2, y[2], x[2]);
    inverseKinematics(3, y[3], x[3]);
    delay(delayTime);
  }
  
  while(tX > 0){
    tX -= servoStep;
    x[0] -= servoStep;
    x[1] -= servoStep;
    x[2] -= servoStep;
    x[3] -= servoStep;
    inverseKinematics(0, y[0], x[0]);
    inverseKinematics(1, y[1], x[1]);
    inverseKinematics(2, y[2], x[2]);
    inverseKinematics(3, y[3], x[3]);
    delay(delayTime);
  }

  delay(1000);
}

void pitchTestMovement(){
  double servoStep = 0.25;
  int delayTime = 50;
  int i = 0;
  
  while(i < 12){
    i++;
    y[0] += servoStep;
    y[1] += servoStep*2;
    y[2] += 0;
    y[3] += servoStep;
    inverseKinematics(0, y[0], x[0]);
    inverseKinematics(1, y[1], x[1]);
    inverseKinematics(2, y[2], x[2]);
    inverseKinematics(3, y[3], x[3]);
    delay(delayTime);
  }
  while(i > 0){
    i--;
    y[0] -= servoStep;
    y[1] -= servoStep;
    y[2] += servoStep;
    y[3] += servoStep;
    inverseKinematics(0, y[0], x[0]);
    inverseKinematics(1, y[1], x[1]);
    inverseKinematics(2, y[2], x[2]);
    inverseKinematics(3, y[3], x[3]);
    delay(delayTime);
  }
  while(i < 12){
    i++;
    y[0] += servoStep;
    y[1] -= servoStep;
    y[2] += servoStep;
    y[3] -= servoStep;
    inverseKinematics(0, y[0], x[0]);
    inverseKinematics(1, y[1], x[1]);
    inverseKinematics(2, y[2], x[2]);
    inverseKinematics(3, y[3], x[3]);
    delay(delayTime);
  }
  while(i > 0){
    i--;
    y[0] += servoStep;
    y[1] += servoStep;
    y[2] -= servoStep;
    y[3] -= servoStep;
    inverseKinematics(0, y[0], x[0]);
    inverseKinematics(1, y[1], x[1]);
    inverseKinematics(2, y[2], x[2]);
    inverseKinematics(3, y[3], x[3]);
    delay(delayTime);
  }
  while(i < 12){
    i++;
    y[0] -= servoStep*2;
    y[1] -= servoStep;
    y[2] -= servoStep;
    y[3] += 0;
    inverseKinematics(0, y[0], x[0]);
    inverseKinematics(1, y[1], x[1]);
    inverseKinematics(2, y[2], x[2]);
    inverseKinematics(3, y[3], x[3]);
    delay(delayTime);
  }
}

// --- essensials

void inverseKinematics(int legIndex, double torsoHeight, double x){
  
  double theta = atan( tan( x / torsoHeight ) ) * 57296 / 1000;
  double cNew = sqrt(torsoHeight*torsoHeight + x*x);

  if(cNew < 0){
    cNew *= -1;
  }
  
  int a = legLenght;
  int b = a;
  double c = cNew;

  int kneeServoIndex = leg[legIndex][0];
  int kneeMin = servoRoms[legIndex][0];
  int kneeAngle = cosineTheorem(a, b, c);
  int femurServoIndex = leg[legIndex][1];
  int femurMax = servoRoms[legIndex][3];
  int femurAngle = 90 - cosineTheorem(a, c, b);
  femurAngle += theta;

  //knee
  HCPCA9685.Servo(kneeServoIndex, map(kneeMin + kneeAngle, 0, 180, 1, 450));
  
  //femur
  HCPCA9685.Servo(femurServoIndex, map(femurMax - femurAngle, 0, 180, 1, 450));

  //hip
  int hipServoIndex = leg[legIndex][2];
  //the value bellow is meant to be a temporary patch
  //TODO: to set default hip servo pos to 90 degrees
  int hipMiddleAngle = servoRoms[legIndex][4];
  HCPCA9685.Servo(hipServoIndex, map(hipMiddleAngle, 0, 180, 1, 450));

}

double cosineTheorem(int a, int b, double c){
  if (c == 0){
    return 0;
  }
  else{
    return acos((b * b + a * a - c * c)/(2.0 * b * a)) * 57296 / 1000;
  }
}

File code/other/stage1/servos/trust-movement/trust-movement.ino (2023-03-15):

#include "HCPCA9685.h"

//must have:
// - array with min and max values
// - inverse kinematics

#define  I2CAdd 0x40
HCPCA9685 HCPCA9685(I2CAdd);

//int servoRoms[12][12] = {{72, 180}, {22, 170}, {0, 0}, {10, 140}, {0, 180}, {0, 0}, {0, 70}, {35, 70}, {0, 0}, {10, 60}, {35, 140}, {0, 0}};
//                      c             c           c            c           c           c           c             c
int servoRoms[4][6] = {{40, 180, 90, 170, 0, 0}, {3, 120, 85, 156, 0, 0}, {0, 115, 90, 150, 0, 0}, {0, 115, 100, 180, 0, 0}};
//the legs need to be closed at the start of the program for the angles to be true
int servoCurrentAngles[4][3] = {{40, 170, 0}, {3, 156, 0}, {0, 150, 0}, {0, 180, 0}};
int leg[4][3] = {{0, 1, 2}, {3, 4, 5}, {6, 7, 8}, {9, 10, 11}};

int legLenght = 10;

void setup() {
  //init the servo driver
  HCPCA9685.Init(SERVO_MODE);
  HCPCA9685.Sleep(false);

  //what i want:
  // - when the program starts move the body to lowered position
  // - stand up

  //make the robot to sit down
  inverseKinematics(0, 0);
  inverseKinematics(1, 0);
  inverseKinematics(2, 0);
  inverseKinematics(3, 0);
  
  // init pause
  delay(750);
}

void loop() {
  standUp();
  delay(3000);
  
  trustMovement();
  standUp();
  trustMovement();
  standUp();
  delay(3000);
}

// --- up and down

void standUp(){
  
  int i = 0;

//  while(servoCurrentAngles[0][1] != servoRoms[0][3] - cosineTheorem(legLenght, legLenght, targetTorso)/2 ){
  while(i < 50){
    inverseKinematicsDelayed(0, 11);
    inverseKinematicsDelayed(1, 11);
    inverseKinematicsDelayed(2, 11);
    inverseKinematicsDelayed(3, 11);
    delay(50);
    i++;
  }
  
}

void trustMovement(){
  
  inverseKinematics(0, 0);
  inverseKinematics(1, 0);
  inverseKinematics(2, 0);
  inverseKinematics(3, 0);
  int i = 11;
  
  while(i > 1){
    inverseKinematicsDelayed(0, i);
    inverseKinematicsDelayed(1, i);
    delay(50);
    i-=0.03;
  }
  
  
}

// --- inverse kinematics

void inverseKinematicsDelayed(int legIndex, double torsoHeight){
  // --- improved version of inverseKinematics() ---
  // provides smooth movement to the calculated target angle
  // !!! this function needs to be looped inside ' loop() '
  
  int a = legLenght; 
  int b = a;
  double c = torsoHeight;

  int kneeServoIndex = leg[legIndex][0]; 
  int kneeMin = servoRoms[legIndex][0]; 
  int kneeAngle = cosineTheorem(a, b, c)/2; 
  int femurServoIndex = leg[legIndex][1]; 
  int femurMin = servoRoms[legIndex][2];
  int femurMax = servoRoms[legIndex][3];
  int femurAngle = cosineTheorem(a, c, b)/2; 

  if (kneeMin + kneeAngle != servoCurrentAngles[legIndex][0]) {
    // check to see if we add to or remove from the current angle 
    // the direction check is inside the leg movement 'if' because we need to check ' kneeAngle != servoCurrentAngles[legIndex][0] '
    
    int kneeDirectionAngle;
    if(kneeMin + kneeAngle > servoCurrentAngles[legIndex][0]) { // 33
      kneeDirectionAngle = 1;
    }
    else{
      kneeDirectionAngle = -1;
    }
  
    // actual knee movement
    HCPCA9685.Servo(kneeServoIndex, map(servoCurrentAngles[legIndex][0] + kneeDirectionAngle, 0, 180, 1, 450));
    servoCurrentAngles[legIndex][0] += kneeDirectionAngle;
  }
  
  if (femurMax - femurAngle != servoCurrentAngles[legIndex][1]) {
    // check to see if we add to or remove from the current angle 
    // the direction check is inside the leg movement 'if' because we need to check ' femurAngle != servoCurrentAngles[legIndex][1] '
    int femurDirectionAngle;
    if(femurMax - kneeAngle > servoCurrentAngles[legIndex][0]) {
      femurDirectionAngle = 1;
    }
    else{
      femurDirectionAngle = -1;
    }
    
    // actual femur movement
    HCPCA9685.Servo(femurServoIndex, map(servoCurrentAngles[legIndex][1] - femurDirectionAngle, 0, 180, 1, 450));
    servoCurrentAngles[legIndex][1] -= femurDirectionAngle;
  }
  
} 

void inverseKinematics(int legIndex, double torsoHeight){
  int a = legLenght;
  int b = a;
  double c = torsoHeight;

  int kneeServoIndex = leg[legIndex][0];
  int kneeMin = servoRoms[legIndex][0];
  int kneeAngle = cosineTheorem(a, b, c)/2;
  int femurServoIndex = leg[legIndex][1];
  int femurMin = servoRoms[legIndex][2];
  int femurMax = servoRoms[legIndex][3];
  int femurAngle = cosineTheorem(a, c, b)/2;

  //knee
  HCPCA9685.Servo(kneeServoIndex, map(kneeMin + kneeAngle, 0, 180, 1, 450));
  
  //femur
  HCPCA9685.Servo(femurServoIndex, map(femurMax - femurAngle, 0, 180, 1, 450));
}

double cosineTheorem(int a, int b, double c){
  if (c == 0){
    return 0;
  }
  else{
    return acos((b * b + a * a - c * c)/(2.0 * b * a)) * 57296 / 1000;
  }
}

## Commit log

2022-11-03 started working on real sized femur
    [femur.FCStd, lowerLeg-Body.3mf]
2022-11-07 working on the femur
    [femur.FCStd]
2022-11-10 finished the femur
    [femur-MainBody.stl, femur.FCStd, femur_messy.FCStd]
2022-11-12 finished the knee
    [knee-Body.stl, knee.FCStd, knee_concept.FCStd]
2022-12-09 all leg parts
    [hip-female.FCStd, hip-female.stl, hip-joint-pin-Body.stl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]
2022-12-14 Body Work
    Body files
    [HipToBody(reversed).FCStd, HipToBody.FCStd, OtherBodyParts.FCStd]
2022-12-14 Complete Body
    :v: :smile:
    [HipToBody(Without Full Connectors).FCStd, HipToBody(reversed).FCStd, HipToBody.FCStd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]
2022-12-15 updated legs
    [femur-MainBody.stl, femur.FCStd, knee-Body.stl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]
2022-12-18 Female hip part with connectors, finally
    ✌️ 😄
    [hip-female(With Connectors).FCStd]
2022-12-21 Reversed hip to body connection, fixed
    [HipToBody(reversed-fixed).FCStd]
2022-12-22 enhanced version of the "OtherBodyParts". ✌️ 😄
    [OtherBodyParts(Enhanced).FCStd]
2023-01-09 added improvements
    [HipToBody.stl, HipToBodyFixed (1).stl, HipToBodyFixed.stl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]
2023-01-11 final body fixes
    [OtherBodyParts_Featherweight-fixed.FCStd, l1.stl, l2-2.0.1.stl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]
2023-01-11 fixed reversed ✌️ 😄
    [HipToBody(reversed-fixed-fixedagain).FCStd]
2023-01-11 updated render
    [render.FCStd, render.stl]
2023-01-11 render fixed fixed
    [render.FCStd]
2023-01-15 reorganized directory
    [HipToBody(Without Full Connectors).FCStd, HipToBody(reversed).FCStd, HipToBody(reversed-fixed).FCStd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]
2023-01-17 prettified readme
    [Unnamed-hip-femaleWith_Connectors2-right.stl]
2023-02-20 hustle legs
2023-02-23 added inverse kinematics
2023-03-01 improving the inverse kinematics
2023-03-04 fixed the normal ik
    [main.ino]
2023-03-13 questionable arduino code
2023-03-28 current movement demo
2023-03-29 added pitch movement
2023-04-04 problema e v ik
    [main.cpp]
2023-04-04 ne e tam problema
    [main.cpp]
2023-04-07 hip servos now lock
2023-04-07 trust™
2023-04-11 да вървим 👉🏿 👶🏿 👈🏿
2023-04-12 да вървим 👉🏿 👶🏿 👈🏿 vol.2
2023-04-12 ultrasonic holder
    [ultrasonicHolder-Body.stl, ultrasonicHolder.FCStd]
2023-04-12 holder sorted
    [ultrasonicHolder.FCStd, ultrasonicHolderTRUST.stl]
2023-04-12 finally holder
    [ultrasonicHolderTRUST.stl]
2023-04-13 primal exoskeleton
    [exoskeleton parts.FCStd]
2023-04-21 leg 2 offset fixed
    [main.cpp]
2023-04-21 ultrasonics working extra
2023-04-21 gyro code
2023-04-21 final app + fix arduino last 3 funcs
    [main.cpp]
2023-04-21 hardware updated
    [OtherBodyParts_Featherweight-fixed.FCStd]
2023-04-22 Added stop button
2023-04-22 adjusted leg 3 hip angle
2023-04-22 added hc-05 holder
    [hc-05-holder.FCStd]
2023-04-22 redid pitch - x
2023-04-22 walking with pitch
